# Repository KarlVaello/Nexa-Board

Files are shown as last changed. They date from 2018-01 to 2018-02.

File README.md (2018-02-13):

<p align="center">
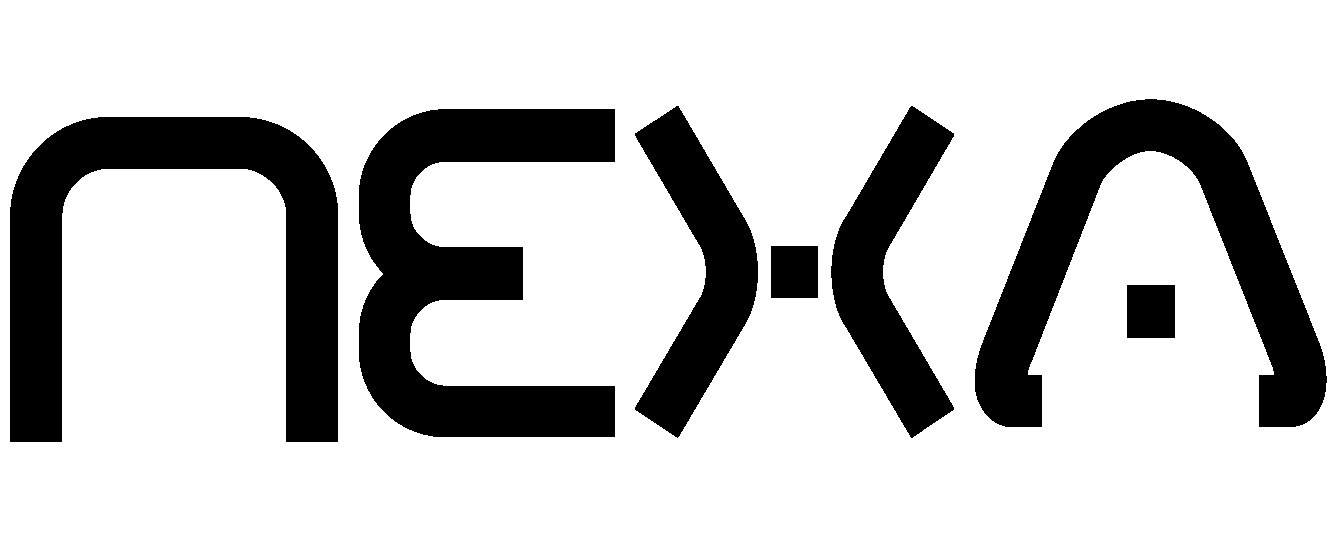
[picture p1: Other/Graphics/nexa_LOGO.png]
  
</p>
<p align="center">
  
</p>

### NOTES!

In need of satisfying the ISO 15765-2 the board will receive hardware changes.

ISO 15765-2, or ISO-TP (Transport Layer), is an international standard for sending data packets over a CAN-Bus. The protocol allows for the transport of messages that exceed the eight byte maximum payload of CAN frames. ISO-TP segments longer messages into multiple frames, adding metadata that allows the interpretation of individual frames and reassembly into a complete message packet by the recipient. It can carry up to 4095 bytes of payload per message packet.

Full duplex RS-485 will be replaced by CAN-bus.

### What is Nexa-Board?
Nexa-Board is an open source project, based on STM32F103 microcontroller with a full duplex RS-485 to create a multipoint network that allows receiving and sending the information of all the boards.
RS-485 as a physical layer and by programming you can set your own data exchange and interpretation protocol.

Hardware characteristics
-	72 MHz
-	Full duplex RS-485 fully configurable.
- CAN-BUS
-	17 GPIO pins
- 7 to 15 V power input
-	Power input polarity protection

### Why does it exist ?
Exist as a solution to get a fully configurable comunication protocol, that allow you to create your own protocol depending on your needs.

### Getting Started
- Get a Nexa Board

### Project that use Nexa-Board
- Nexa Home

### TODO 
- [x] Board design (Schematic)
- [x] Board design (PCB)
- [x] PCB manufacture
- [ ] HW test
- [ ] HW final version
---------------
- [ ] New hardware changes due to apply CAN-bus
- [x] Board design (Schematic)
- [x] Board design (PCB)
- [x] PCB manufacture
- [ ] HW test
- [ ] HW final version

### Releases
 | [v1.0](https://github.com/KarlVaello/Nexa-Board/releases/tag/v1.0) - Initial complete board concept

### License
- [GPL-3.0](https://github.com/KarlVaello/Nexa-Board/blob/master/LICENSE.md)

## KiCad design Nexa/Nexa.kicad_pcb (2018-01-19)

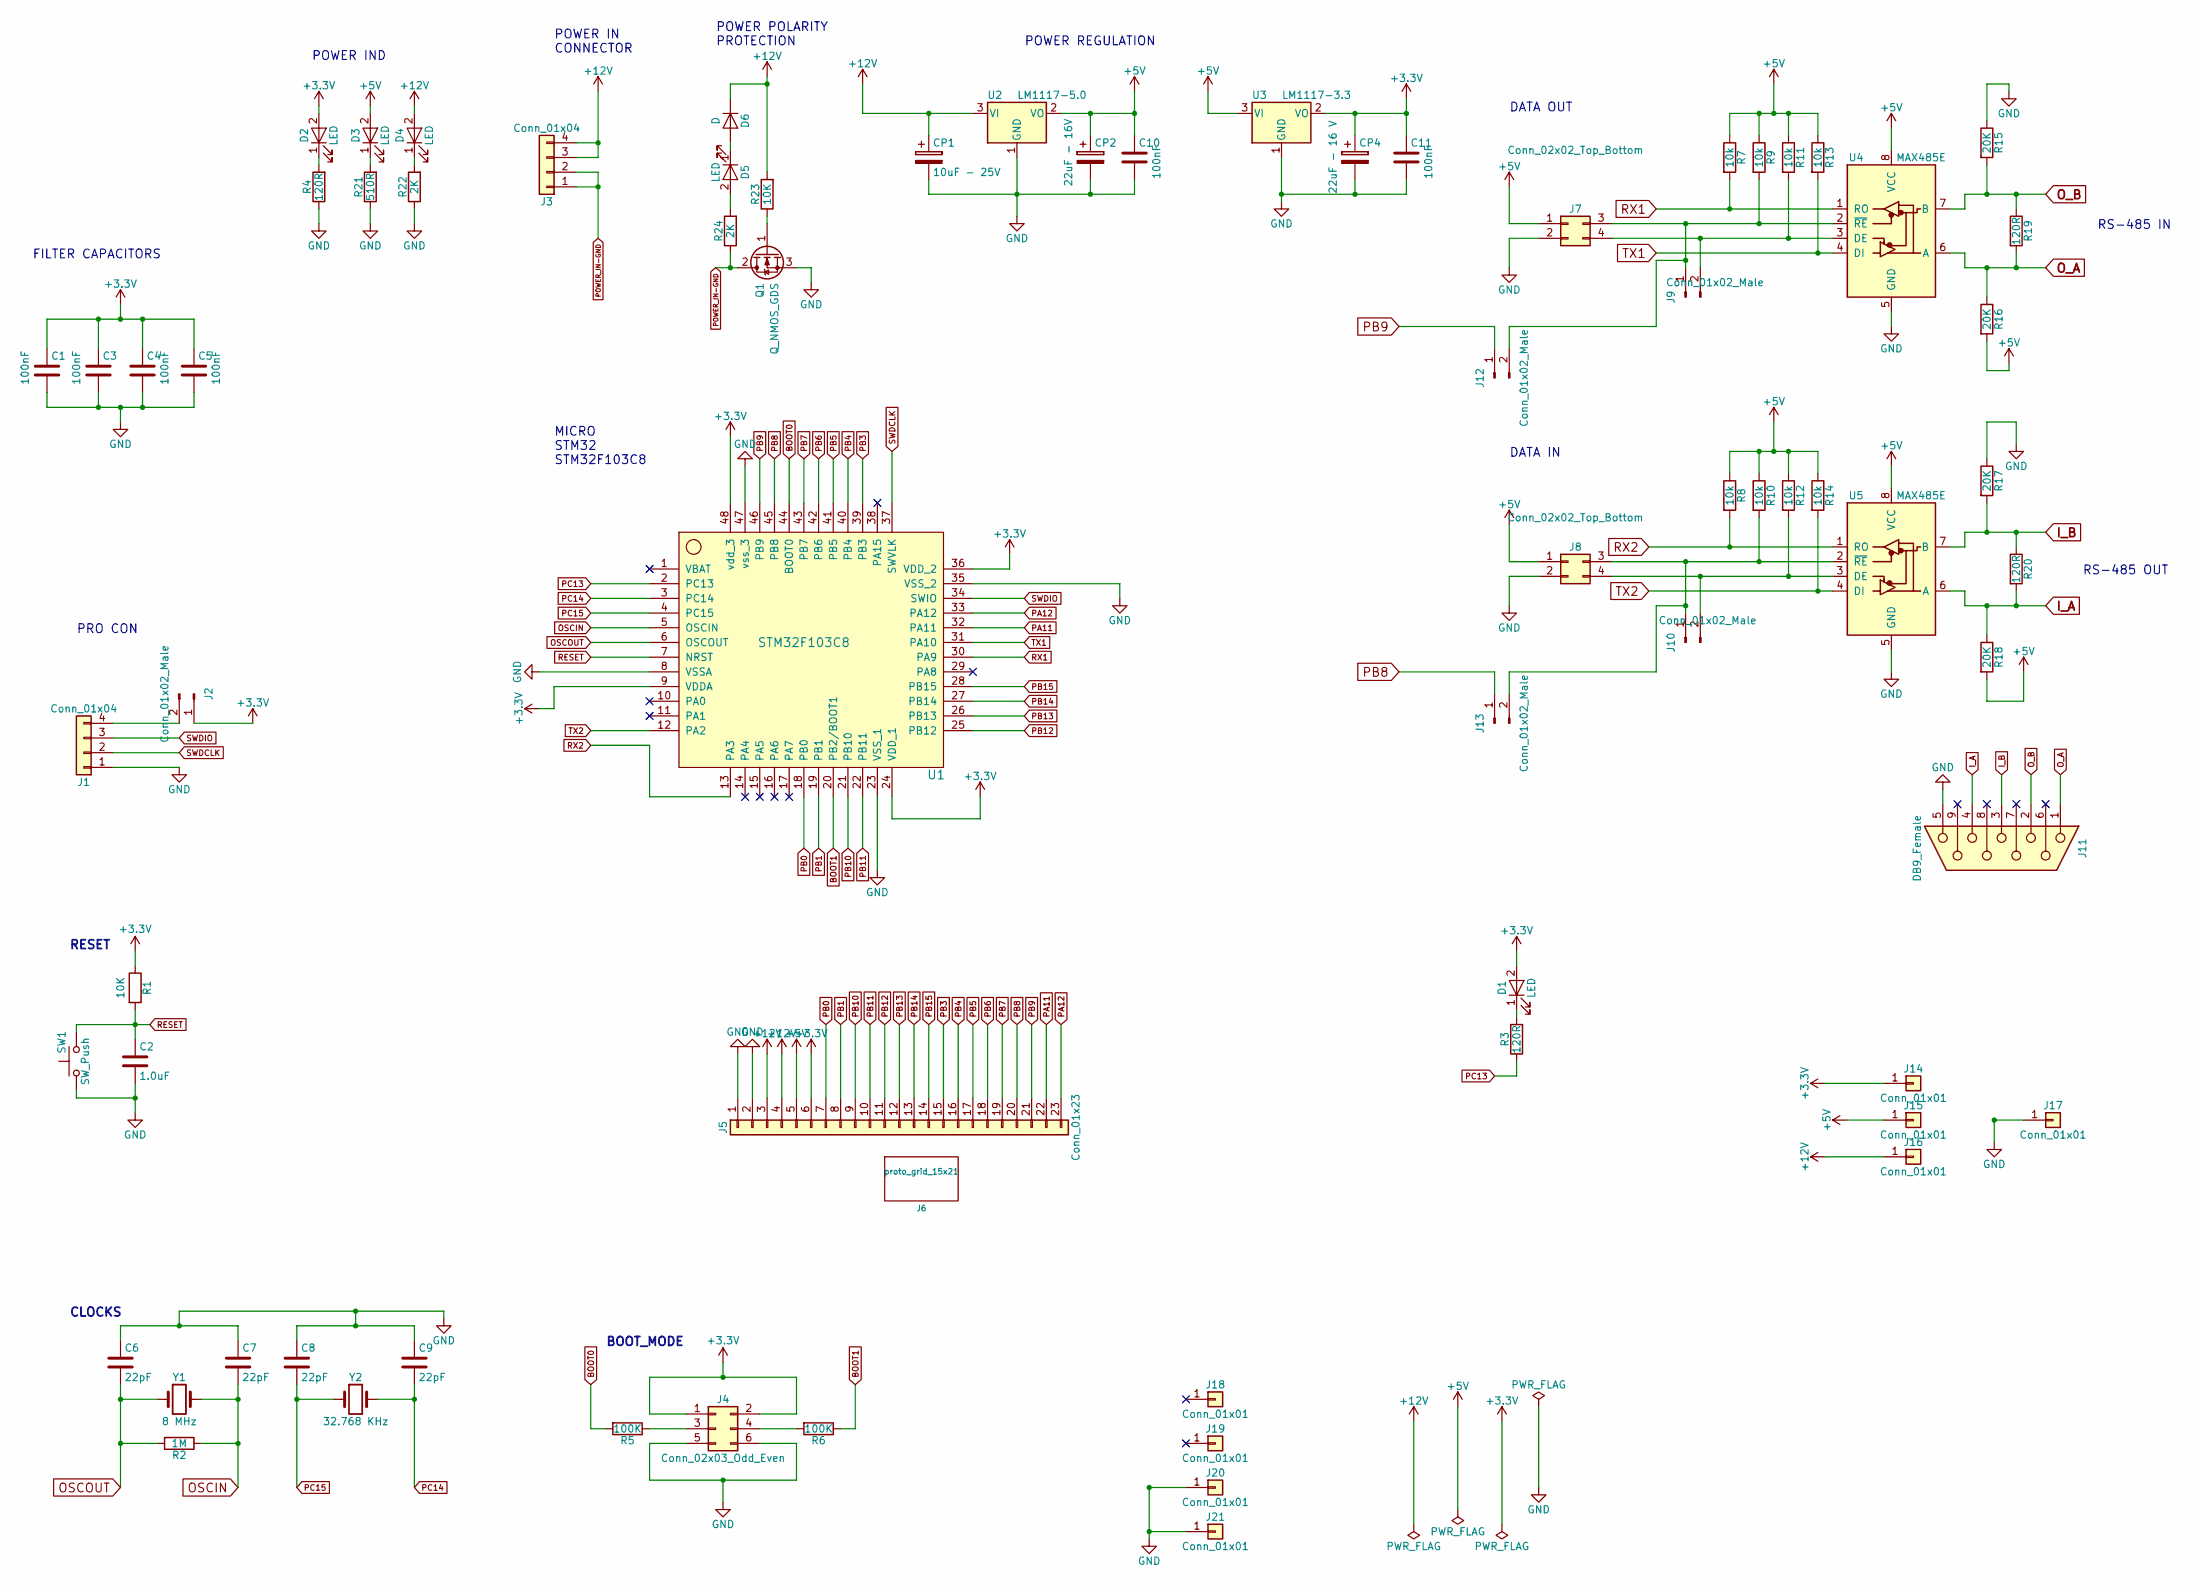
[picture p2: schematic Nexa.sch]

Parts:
C1, C3, C4, C5: 100nF; C_0603_HandSoldering
C2: 1.0uF; C_0603_HandSoldering
C6, C7, C8, C9: 22pF; C_0603_HandSoldering
C10, C11: 100nF; C_0805_HandSoldering
CP1: 10uF - 25V; CP_Tantalum_Case-C_EIA-6032-28_Hand
CP2: 22uF - 16V; CP_Tantalum_Case-B_EIA-3528-21_Hand
CP4: 22uF - 16 V; CP_Tantalum_Case-B_EIA-3528-21_Hand
D1, D2, D3, D4, D5: LED; LED_0805_HandSoldering
D6: D; D_SMB
J1: Conn_01x04; Pin_Header_Straight_1x04_Pitch2.54mm
J2, J9, J10, J12, J13: Conn_01x02_Male; Pin_Header_Straight_1x02_Pitch2.54mm
J3: Conn_01x04; Molex_MiniFit-JR-5569-04A2_2x02x4.20mm_Angled
J4: Conn_02x03_Odd_Even; Pin_Header_Straight_2x03_Pitch2.54mm
J5: Conn_01x23; Socket_Strip_Straight_1x23_Pitch2.54mm
J6: proto_grid_15x21; grid
J7, J8: Conn_02x02_Top_Bottom; Pin_Header_Straight_2x02_Pitch2.54mm
J11: DB9_Female
J14, J15, J16: Conn_01x01; Pin_Header_Straight_1x01_Pitch2.54mm
J17: Conn_01x01; Measurement_Point_Round-TH_Small
J18, J19, J20, J21: Conn_01x01; MountHoles_H3.2mm_D5.5
Q1: Q_NMOS_GDS; TO-252-2
R1, R23: 10K; R_0603_HandSoldering
R2: 1M; R_0603_HandSoldering
R3, R4, R19, R20: 120R; R_0603_HandSoldering
R5, R6: 100K; R_0603_HandSoldering
R7, R8, R9, R10, R11, R12, R13, R14: 10k; R_0603_HandSoldering
R15, R16, R17, R18: 20K; R_0603_HandSoldering
R21: 510R; R_0603_HandSoldering
R22, R24: 2K; R_0603_HandSoldering
SW1: SW_Push; SW_PUSH_6mm_h8.5mm
U1: STM32F103C8; LQFP-48_7x7mm_Pitch0.5mm
U2: LM1117-5.0; SOT-223
U3: LM1117-3.3; SOT-223
U4, U5: MAX485E; SOIC-8_3.9x4.9mm_Pitch1.27mm
Y1: 8 MHz; Crystal_HC49-4H_Vertical
Y2: 32.768 KHz; Crystal_SMD_SeikoEpson_MC306-4pin_8.0x3.2mm_HandSoldering

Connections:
+3V3: C1.1, C3.1, C4.1, C5.1, C11.1, CP4.1, D1.2 (A), D2.2 (A), J2.1, J4.1, J4.2, J5.6, J14.1, R1.1, U1.9 (VDDA), U1.24 (VDD_1), U1.36 (VDD_2), U1.48 (vdd_3), U3.2 (VO)
+5V: C10.1, CP2.1, D3.2 (A), J5.5, J7.1, J8.1, J15.1, R7.1, R8.1, R9.1, R10.1, R11.1, R12.1, R13.1, R14.1, R16.2, R18.2, U2.2 (VO), U3.3 (VI), U4.8 (VCC), U5.8 (VCC)
+12V: CP1.1, D4.2 (A), D6.1 (K), J3.3, J3.4, J5.3, J5.4, J16.1, R23.2, U2.3 (VI)
BOOT0: R5.2, U1.44 (BOOT0)
BOOT1: R6.1, U1.20 (PB2/BOOT1)
GND: C1.2, C2.2, C3.2, C4.2, C5.2, C6.1, C7.1, C8.1, C9.1, C10.2, C11.2, CP1.2, CP2.2, CP4.2, J1.1, J4.5, J4.6, J5.1, J5.2, J7.2, J8.2, J11.5, J17.1, J20.1, J21.1, Q1.3 (S), R4.1, R15.1, R17.1, R21.1, R22.1, SW1.1, U1.8 (VSSA), U1.23 (VSS_1), U1.35 (VSS_2), U1.47 (vss_3), U2.1 (GND), U3.1 (GND), U4.5 (GND), U5.5 (GND)
I_A: J11.4, R18.1, R20.2, U5.6 (A)
I_B: J11.3, R17.2, R20.1, U5.7 (B)
unnamed: D1.1 (K), R3.2
unnamed: D2.1 (K), R4.2
unnamed: D3.1 (K), R21.2
unnamed: D4.1 (K), R22.2
unnamed: D5.1 (K), D6.2 (A)
unnamed: D5.2 (A), R24.2
unnamed: J1.4, J2.2
unnamed: J4.3, R5.1
unnamed: J4.4, R6.2
unnamed: J7.4, J9.2, R11.2, U4.3 (DE)
unnamed: J8.3, J10.1, J13.2, R10.2, U5.2 (~RE)
unnamed: J8.4, J10.2, R12.2, U5.3 (DE)
unnamed: J7.3, J9.1, J12.2, R9.2, U4.2 (~RE)
unnamed: Q1.1 (G), R23.1
OSCIN: C7.2, R2.1, U1.5 (OSCIN), Y1.2
OSCOUT: C6.2, R2.2, U1.6 (OSCOUT), Y1.1
O_A: J11.1, R16.1, R19.2, U4.6 (A)
O_B: J11.2, R15.2, R19.1, U4.7 (B)
PA11: J5.22, U1.32 (PA11)
PA12: J5.23, U1.33 (PA12)
PB0: J5.7, U1.18 (PB0)
PB1: J5.8, U1.19 (PB1)
PB3: J5.15, U1.39 (PB3)
PB4: J5.16, U1.40 (PB4)
PB5: J5.17, U1.41 (PB5)
PB6: J5.18, U1.42 (PB6)
PB7: J5.19, U1.43 (PB7)
PB8: J5.20, J13.1, U1.45 (PB8~)
PB9: J5.21, J12.1, U1.46 (PB9)
PB10: J5.9, U1.21 (PB10)
PB11: J5.10, U1.22 (PB11)
PB12: J5.11, U1.25 (PB12)
PB13: J5.12, U1.26 (PB13)
PB14: J5.13, U1.27 (PB14)
PB15: J5.14, U1.28 (PB15)
PC13: R3.1, U1.2 (PC13)
PC14: C9.2, U1.3 (PC14), Y2.2
PC15: C8.2, U1.4 (PC15), Y2.1
POWER_IN-GND: J3.1, J3.2, Q1.2 (D), R24.1
RESET: C2.1, R1.2, SW1.2, U1.7 (NRST)
RX1: R7.2, U1.30 (PA9), U4.1 (RO)
RX2: R8.2, U1.13 (PA3), U5.1 (RO)
SWDCLK: J1.2, U1.37 (SWVLK)
SWDIO: J1.3, U1.34 (SWIO)
TX1: R13.2, U1.31 (PA10), U4.4 (DI)
TX2: R14.2, U1.12 (PA2), U5.4 (DI)

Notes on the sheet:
DATA OUT
DATA IN
RESET
CLOCKS
BOOT_MODE
FILTER CAPACITORS
POWER REGULATION
RS-485 IN
RS-485 OUT
POWER IND
POWER POLARITY PROTECTION
POWER IN CONNECTOR
PRO CON
MICRO STM32 STM32F103C8

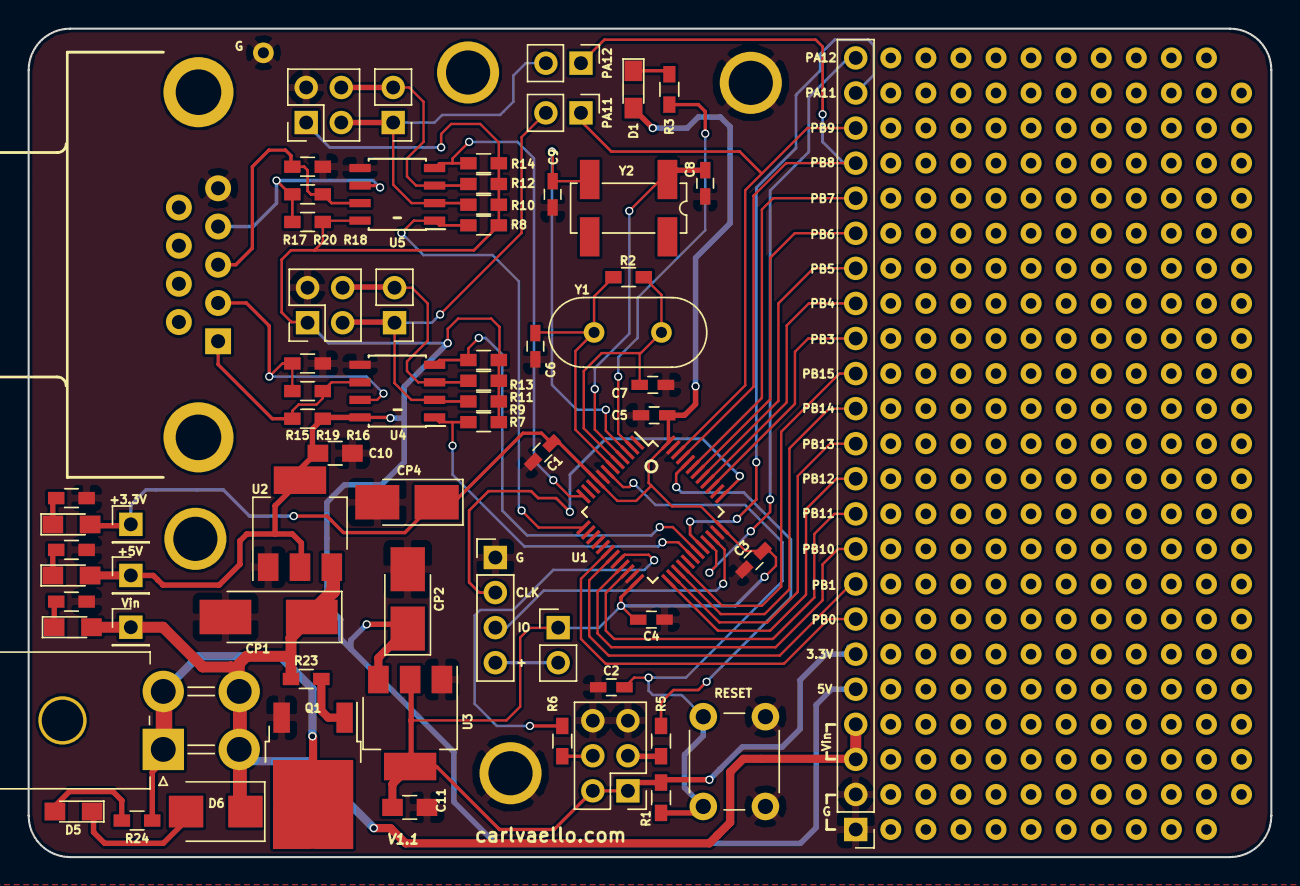
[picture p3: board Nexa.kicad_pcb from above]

Board: 2 copper layers, 90.0 x 60.0 mm, 74 parts (0 on the bottom side), 54 nets.

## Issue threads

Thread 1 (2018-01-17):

Polarity protection N_Mosfet is NOT correct configured (V1.0)

KarlVaello, 2018-01-17:
Polarity protection N_Mosfet is NOT correct configured.
This bug is in1.0 pcb version.
Exchange Pin 1 and 2. To do this you have to replace the component with the appropriate drawing in the schematic. And correct the PCB.

Closed 2018-01-18.

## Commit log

2018-01-11 Board Hardware files
    Hardware files on KiCad v1.0
    [Nexa.kicad_pcb, Nexa.sch]
2018-01-19 Issue #1 and #2 closed
    #1 Polarity protection N_Mosfet is NOT correct configured
    Mosfets had incorrect pinout.
    #2 CP1 (10nF-16V), max V should be oversize
    CP1 is now a 25V cap
    [Nexa.kicad_pcb, Nexa.sch]
2018-02-13 CHANGES - CAN BUS
